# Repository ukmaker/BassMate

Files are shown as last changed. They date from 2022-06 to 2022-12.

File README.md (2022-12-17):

# BassMate

This is a simple drum machine and sequencer.

I want to be able to quickly create simple rhythm sequences to help me pratice electric bass, and was looking for something between a basic metronome and a full-fledged DAW.
The Drumbit online app (https://drumbit.app/) is pretty good, but having to point and click while playing an instrument is not tactile enough for me.
Accordingly, BassedMate (https://github.com/ukmaker/BassedMate) was born. This was the first iteration of the project, using a Teensy.

BassMate (this repo) is an evolution. I wanted to eliminate the VS1053 chip and I found the Electrosmith Daisy Seed (https://www.electro-smith.com/daisy/daisy)
which looked like it could do all the synthesis itself. I also found the MusicBoard project (https://github.com/julbouln/musicboard) which inspired me
to try to port to the Seed. This proved to be tricky, so I gave up (I'll try again one day!) and took a different path.

The UI of BassedMate felt a bit off, and when I came across the NavKey (https://coolcomponents.co.uk/products/i2c-navkey-7-function-joypad-black)
I thought I'd try something different. I also had an STM32F411 BlackPill (https://shop.pimoroni.com/products/stm32f411-blackpill-development-board?variant=39274213343315)
which has tons of memory and is really cheap.

So I remixed everything, sprinkled a new flavour of my GUI library (https://os.mbed.com/users/duncanFrance/code/SimpleGUI/) on the top and am happy with the result.

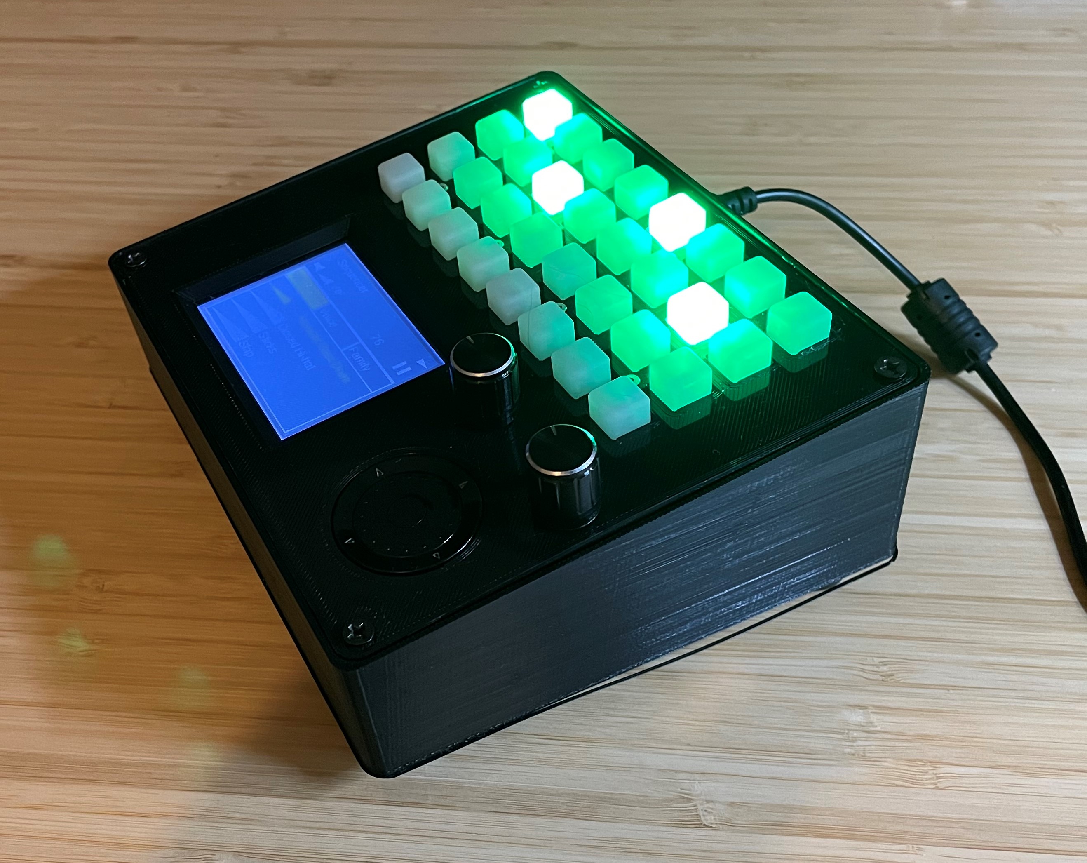
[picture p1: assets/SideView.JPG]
The Finished BassMate


BassMate in action(https://youtu.be/watch?v=EM4BZbcfi_k)

# Installation
This is a PlatformIO project.

Clone this repository somewhere, then get the git submodules:
```
  git clone git@github.com:ukmaker/BassMate.git
  cd BassMate
  git submodule init
  git submodule update
```

Open the folder in PlatformIO, build and deploy as usual.

I have an ST-LINK V2 clone which I use to program Blue- and Black-pills. I throroughly
recommend it since with it you get to debug with single-step etc.

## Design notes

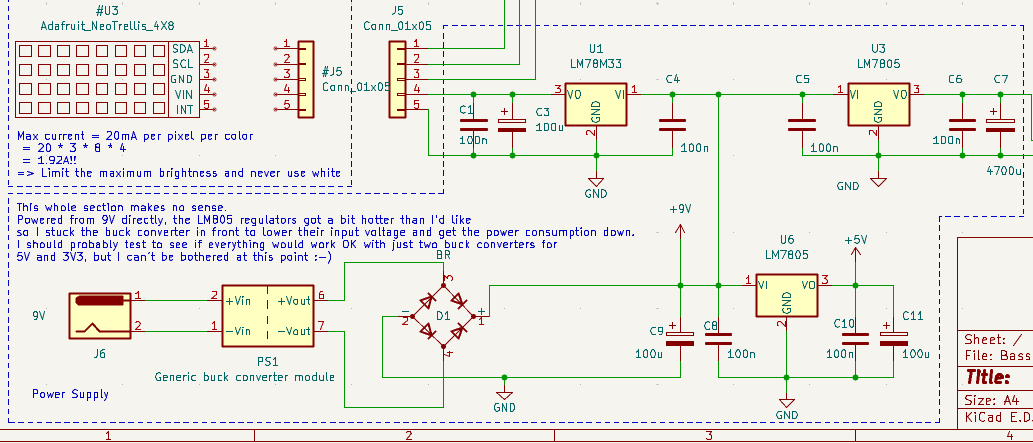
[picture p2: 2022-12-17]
assets/PSU.PNG

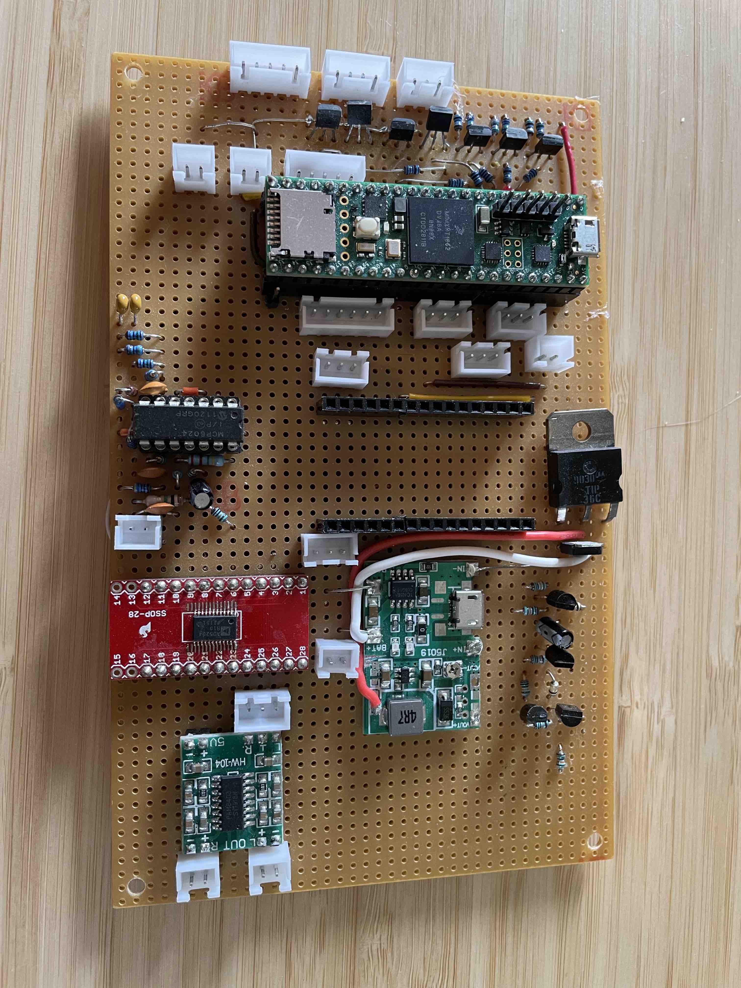
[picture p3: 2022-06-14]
assets/BassedMate-MainBoard.jpeg

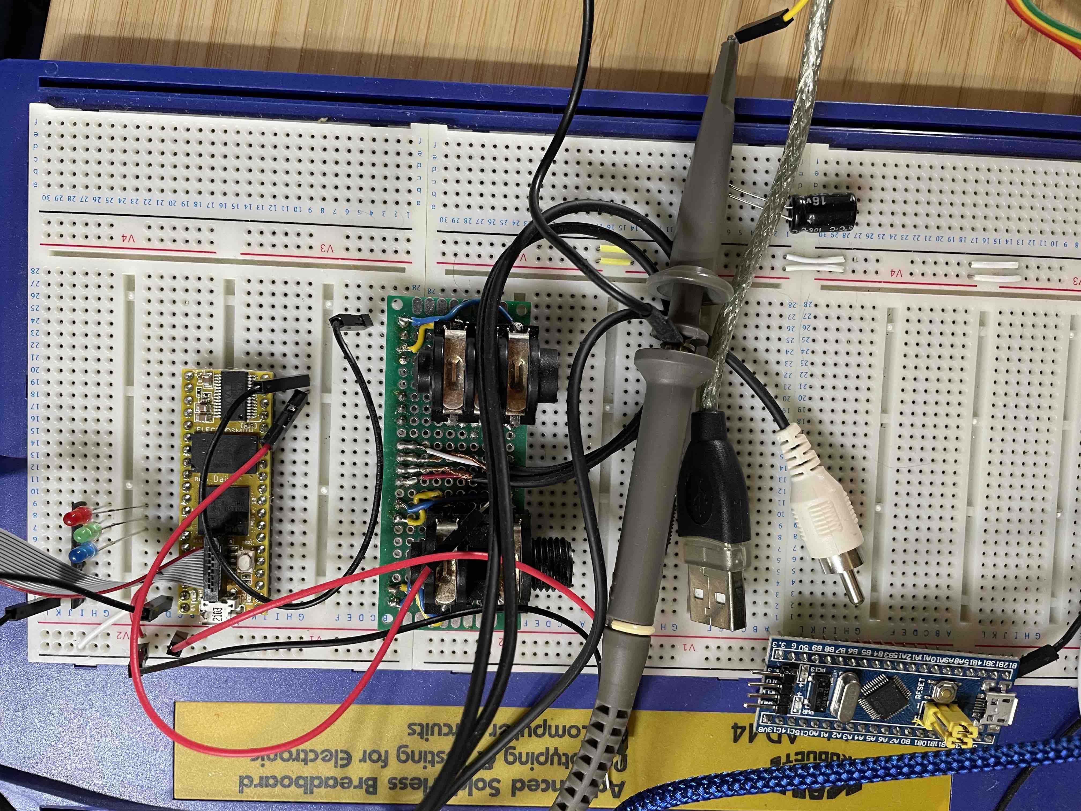
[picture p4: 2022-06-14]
assets/DaisySeed.jpeg

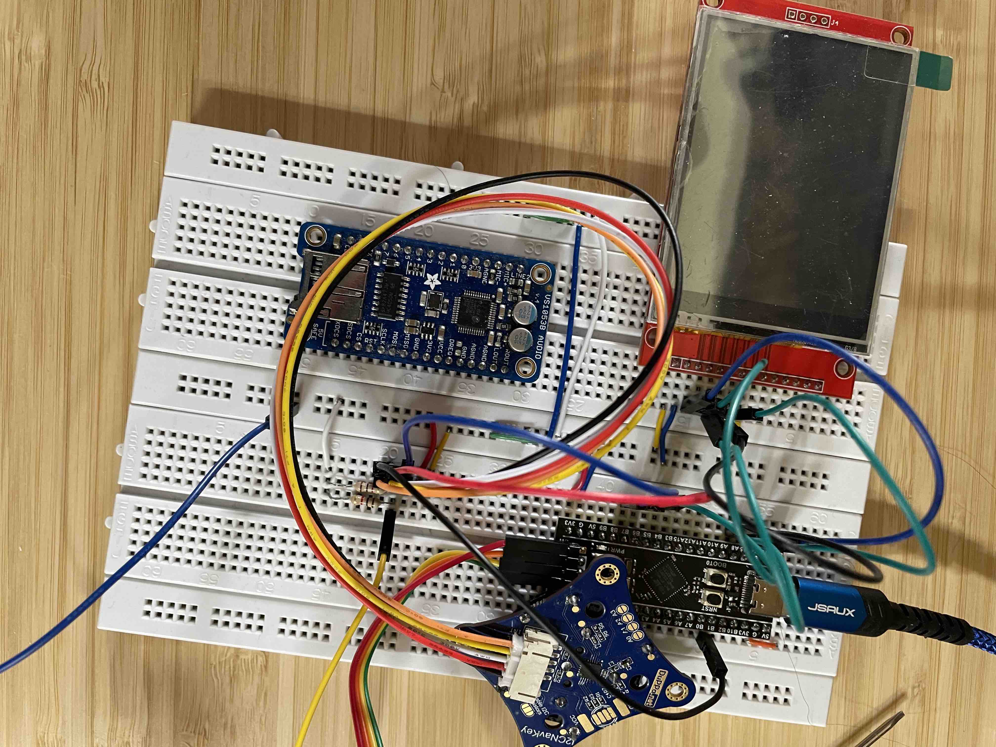
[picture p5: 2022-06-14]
assets/BlackPill.jpeg

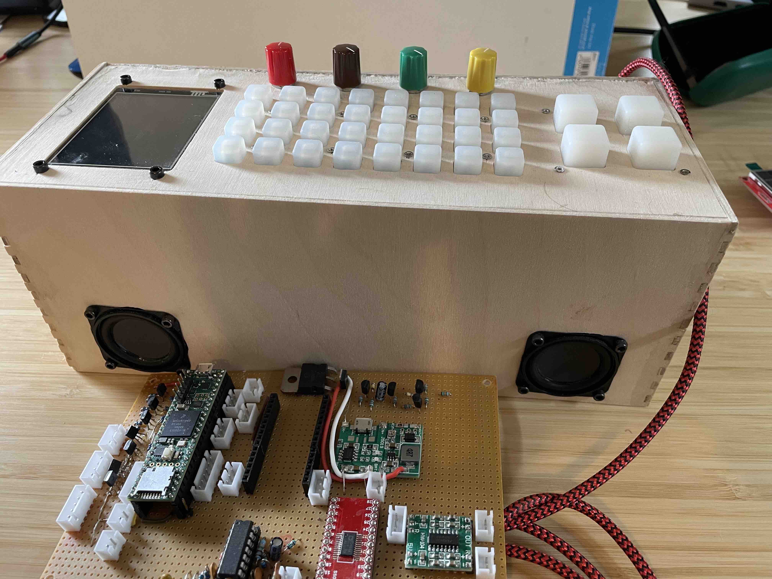
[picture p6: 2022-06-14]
assets/BassedMate-Side.jpeg

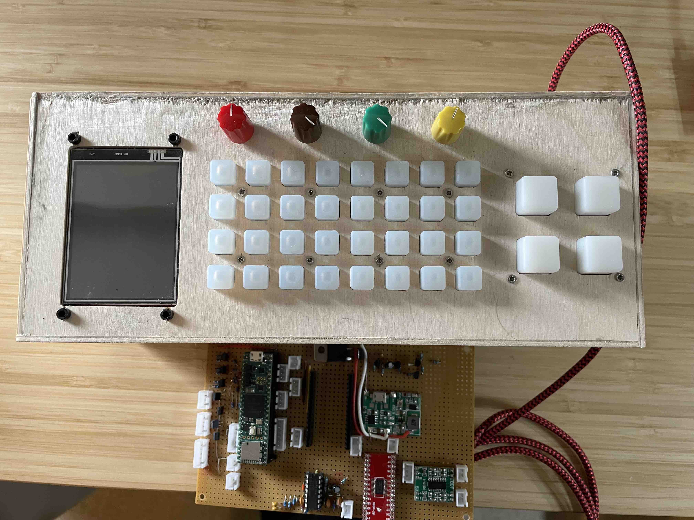
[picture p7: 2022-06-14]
assets/BassedMate-Top.jpeg

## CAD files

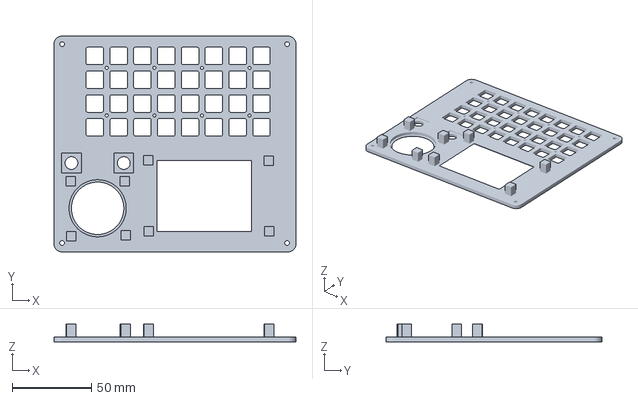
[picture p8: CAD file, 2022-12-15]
Cura/MU_FrontPanelV7.3mf
152.5 x 136.0 x 11.0 mm

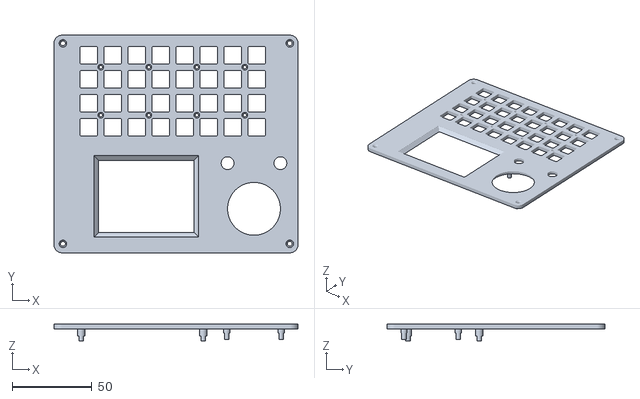
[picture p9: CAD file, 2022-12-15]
OpenSCAD/FrontPanelV7.stl
152.5 x 136.0 x 10.6

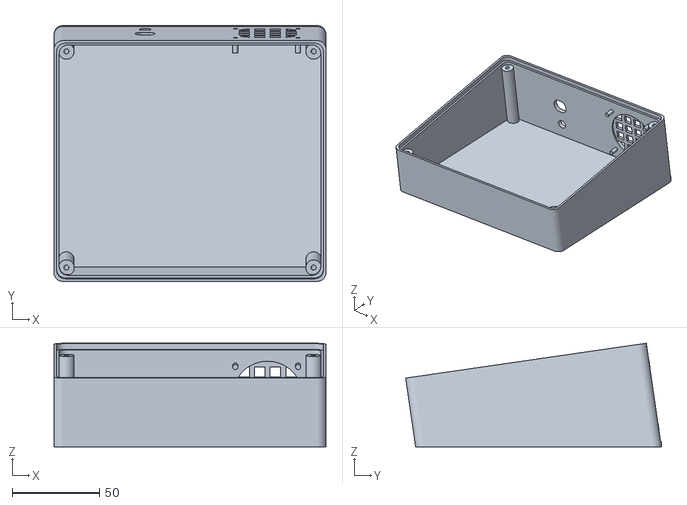
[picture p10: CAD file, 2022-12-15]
OpenSCAD/BassMate-BodyV7.stl
156.0 x 146.7 x 59.4

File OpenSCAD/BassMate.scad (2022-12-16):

include <FrontPanel.scad>
/**
* Uses the pre-release version 0.1 of ukmaker_openscad_lib
**/
include <ukmaker_openscad_lib/Boxes.scad>
$fn = 100;
/**
 * Model of an assembled BassMate
 **/

theta = asin ((20) / box_height);

LAYER_HEIGHT = 0.15;
thickness = 3;
screw_hole_dia = 3;
screw_hole_offset = thickness + 1.5 * screw_hole_dia - LAYER_HEIGHT;

power_socket_thread_dia = 11.5;
power_socket_flats = 10.5;
power_socket_height = 32;

headphones_dia = 6.8;
headphones_height = 15;


module headphone_socket() {

    translate([0,0,-LAYER_HEIGHT])
    cylinder(h = thickness *2, d= headphones_dia);

}

module power_socket() {
    // a cylinder with flats
    dy = (power_socket_thread_dia - power_socket_flats)/2;
    translate([0,0,-LAYER_HEIGHT])
    difference() {
        cylinder(h=thickness*2, d = power_socket_thread_dia);
        translate([-power_socket_thread_dia/2,-power_socket_thread_dia*1.5 + dy,-LAYER_HEIGHT])
        cube([power_socket_thread_dia,power_socket_thread_dia,thickness*3]);
        translate([-power_socket_thread_dia/2,power_socket_thread_dia*.5 - dy,-LAYER_HEIGHT])
        cube([power_socket_thread_dia,power_socket_thread_dia,thickness*3]);
    }
}

module
fitted_panel ()
{
  // THe front panel
  rotate ([ theta, 0, 0 ]) translate ([ thickness / 2, 0 / 2, 40 ]) panel ();
}

module
panel ()
{
  difference ()
  {
    option2 ();
    translate ([ -1.5, -1.5, 0 ])
        op_4_grid (box_width + 3.5, box_height + 3.5, screw_hole_offset,
                   screw_hole_offset, screw_hole_offset, screw_hole_offset)
            countersink (screw_hole_dia, thickness + 2 * LAYER_HEIGHT);
  }
}

module
body ()
{

  sloping_body (box_width + 3.5, box_height + 3.5, 40, 60, 3, 5, 3)
  {

    // Back panel cutouts are laid out on
    // a rectangle the width and rear_height of the boc
    // The sloping_body module rotates to the correct position
    // Speaker cutout on the right


    union() {
        translate ([ box_width - 30, 60 - 30, 0 ]) {                      
            speaker_grille_square(speaker_dia, thickness);
            // inset for the speaker rim
            translate([0,0,thickness-1])
            cylinder(h=speaker_lip+2*LAYER_HEIGHT, d=speaker_dia);
        }
        
        translate([box_width/2 - 24, headphones_height,0])
        headphone_socket();
        translate([box_width/2 - 24, power_socket_height,0])
        power_socket();
    }
    
     translate ([ box_width - 30, 60 - 30, 0 ]){
     union() {
        // holes are on a grid evenly spaced over the speaker
        l = speaker_mounting_hole_grid + 2 * speaker_mounting_hole_dia;
        w = l;
        offset = speaker_mounting_hole_dia/2;
        translate([-speaker_dia/2, -speaker_dia/2, 0])
        op_4_grid(l, w, offset, offset, offset, offset) {
            cylinder(h=speaker_mounting_hole_dia*3,d=speaker_mounting_hole_dia);
        }
    }
    }
  }
}

//fitted_panel ();
//power_socket();
body ();

// panel();

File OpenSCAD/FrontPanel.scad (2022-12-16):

LAYER_HEIGHT = 0.4;
/**
* Uses the pre-release version 0.1 of ukmaker_openscad_lib
**/
use <ukmaker_openscad_lib/Generics.scad>

use <ukmaker_openscad_lib/Standoffs.scad>

use <ukmaker_openscad_lib/TFTs.scad>


use <ukmaker_openscad_lib/I2CNavKey.scad>
include <ukmaker_openscad_lib/I2CNavKey.h>


panel_thickness = 3;

panel_rounding = 5;

trellis_button_side = 11;
trellis_button_grid = 15;
trellis_button_squish = 2;

trellis_width = 60;
trellis_height = 60;

trellis_rows = 4;
trellis_cols = 8;

tbt_side = 15.5;
tbt_grid = 25;

tft_w = 80;
tft_h = 50;

encoder_side = 12.5;
encoder_recess_depth = 1;
encoder_hole_dia = 8;


box_margin = 10;
box_width = tft_w + i2c_navkey_pcb_side + 3 * box_margin;
box_height =  trellis_button_grid * (trellis_rows-1)+ trellis_button_side + 2 * box_margin + tft_h + box_margin;

speaker_dia = 40;
speaker_lip = 1;
speaker_mounting_hole_dia = 3;
speaker_mounting_hole_grid = 33;

module button(h, w, r) {
    linear_extrude(height = h) rounded_square(h, w, r);
}

module buttons(h, w, r, s, rows, cols) {
    
    for(y = [0:rows-1]) {
        for(x = [0:cols-1]) {
            translate([x * s, y * s, 0])
            button(h,w,r);
        }
    }
    
}

module tft() {
    // overall 46x34 (56x34)
    // screen 35x28
    translate([0,0,-1]) {
        color("Red")
        linear_extrude(1)
        square([80,50]);
        
        color("Black")
        linear_extrude(4)
        translate([7.5,0,1])
        square([70,50]);
    }
}

module knob(c) {
    
    translate([0,0,3]) {
        translate([0,0,-10])
    cylinder(h=10, r=3.5);
    color("Grey")
    cylinder(h=18,r=6);
    translate([0,0,18])
    color(c)
    cylinder(h=1,r=6);
    }
}

module knobs() {
    knob("Red");
    
    translate([30,0,0])
    knob("Blue");
    
    translate([60,0,0])
    knob("Green");
    
    translate([90,0,0])
    knob("Black");
    
    
}
        
$fn=100;

module trellis() {
    buttons(trellis_button_side, trellis_button_side, 1, trellis_button_grid, 4, 8);
    
    screw_spacing = trellis_button_side+(trellis_button_grid-trellis_button_side)/2;
    trellis_side = trellis_button_grid*3 + trellis_button_side;
    
    op_4_grid(trellis_side,trellis_side,
    screw_spacing,screw_spacing,screw_spacing,screw_spacing)
    countersink(2,panel_thickness+LAYER_HEIGHT);

    translate([trellis_side+trellis_button_grid - trellis_button_side,0,0])
    op_4_grid(trellis_side,trellis_side,
    screw_spacing,screw_spacing,screw_spacing,screw_spacing)
    countersink(2,panel_thickness+LAYER_HEIGHT);
}

module control_buttons() {
    buttons(tbt_side, tbt_side, 1, tbt_grid, 2, 2);
}

module panel() {
    color("White")
    cube([260, 105, 2.5]);
}

module option1() {
projection()
difference() {
    translate([-10, -20, 0.1])
    panel();

    translate([0, - (tbt_side/2 + tbt_grid/2),0])
    translate([0, (trellis_button_side/2 + trellis_button_grid * 3/2), 0])
    control_buttons();

    translate([tbt_side * 2 + tbt_grid, 0, 0])
    trellis();

    translate([235,-15,0])
    rotate([0,0,90])
    tft();

    translate([70,70,0])
    knobs();
}
}

module i2c_navkey_locate() {
    translate([box_width - i2c_navkey_dia_1/2 - box_margin,i2c_navkey_dia_1/2 + box_margin,-0.1])
    children();
}

module option2() {
    // panel
    difference() {
        
         linear_extrude(height = panel_thickness) rounded_square(box_width, box_height, panel_rounding);

        //cube([box_width, box_height, 2.5]);
        tl = (box_width - trellis_width * 2) / 2;
        translate([tl, trellis_button_grid * 5 - 2, -0.1])
        trellis();
        
        // navkey hole
        i2c_navkey_locate()
        cylinder(h=panel_thickness+LAYER_HEIGHT,d=i2c_navkey_dia_2 + i2c_navkey_rim_clearance);
        
        i2c_navkey_locate()
        cylinder(h=i2c_navkey_joypad_rim_thickness + 1,d=i2c_navkey_dia_1 + 1);
        
        // TFT hole
        translate([box_margin,box_margin,-0.1]) {
        mnt_cutout_bezel_tft_2_8(thickness, panel_thickness+LAYER_HEIGHT);
        }
        
        // encoder holes
        translate([-encoder_side-4, i2c_navkey_pcb_side/2 + encoder_side/2 + 1, -0.1])
        i2c_navkey_locate() {
        cylinder(h=panel_thickness+LAYER_HEIGHT, d=encoder_hole_dia);
        translate([-encoder_side/2,-encoder_side/2,-LAYER_HEIGHT])
        cube([encoder_side,encoder_side,encoder_recess_depth+LAYER_HEIGHT]);
        
        }

        translate([encoder_side+4, i2c_navkey_pcb_side/2 + encoder_side/2 + 1, -0.1])
        i2c_navkey_locate() {
        cylinder(h=panel_thickness+LAYER_HEIGHT, d=encoder_hole_dia);
        translate([-encoder_side/2,-encoder_side/2,-LAYER_HEIGHT])
        cube([encoder_side,encoder_side,encoder_recess_depth+LAYER_HEIGHT]);
        }
    }
        
     
    i2c_navkey_locate() {
        mirror([0,0,1])
        i2c_navkey_melt_standoffs(i2c_navkey_board_offset - panel_thickness + 0.5, 4, LAYER_HEIGHT );
    }
    
    translate([box_margin,box_margin,-LAYER_HEIGHT]) {
       mirror([0,0,1])
        mnt_melt_bezel_tft_2_8(LAYER_HEIGHT);
    }
    translate([box_margin,box_margin,0]) {
        // Add the bezel
        mnt_bezel_tft_2_8(thickness, thickness);
    }
}

//option2();

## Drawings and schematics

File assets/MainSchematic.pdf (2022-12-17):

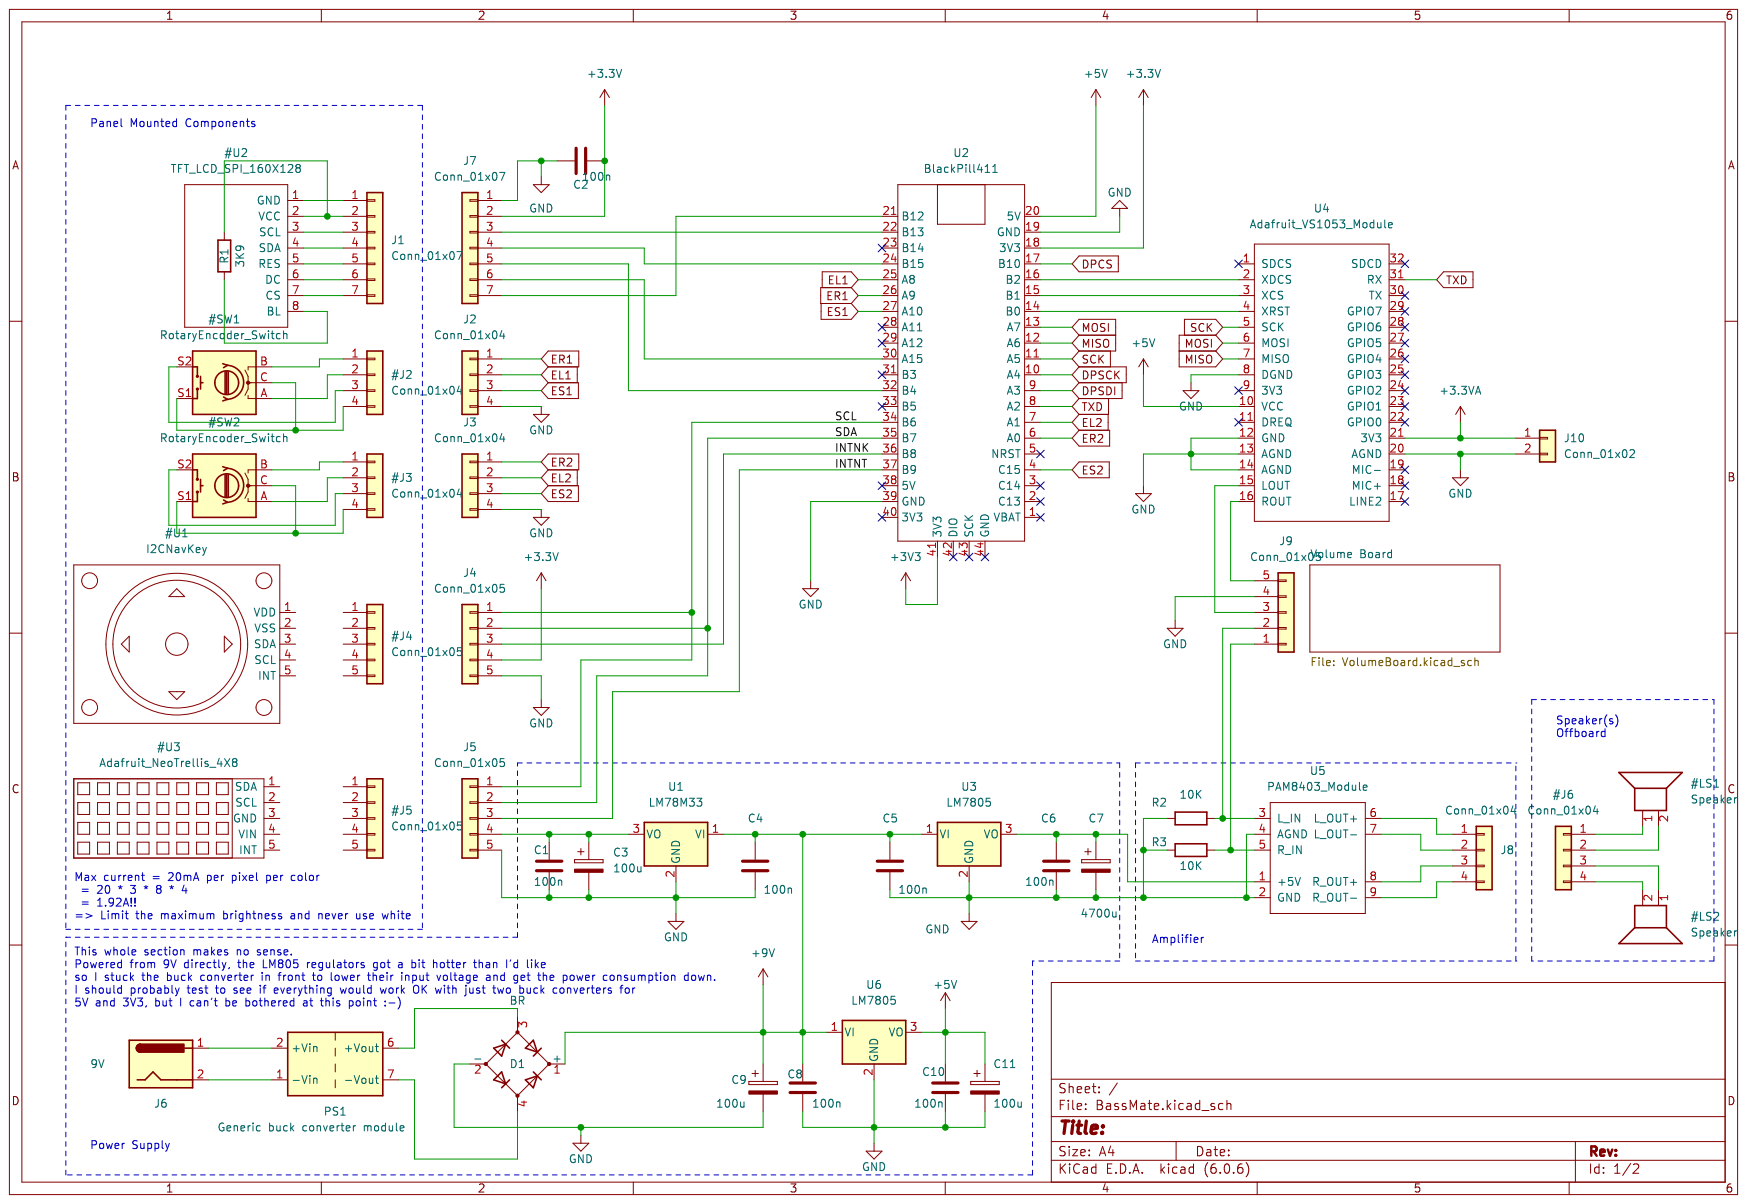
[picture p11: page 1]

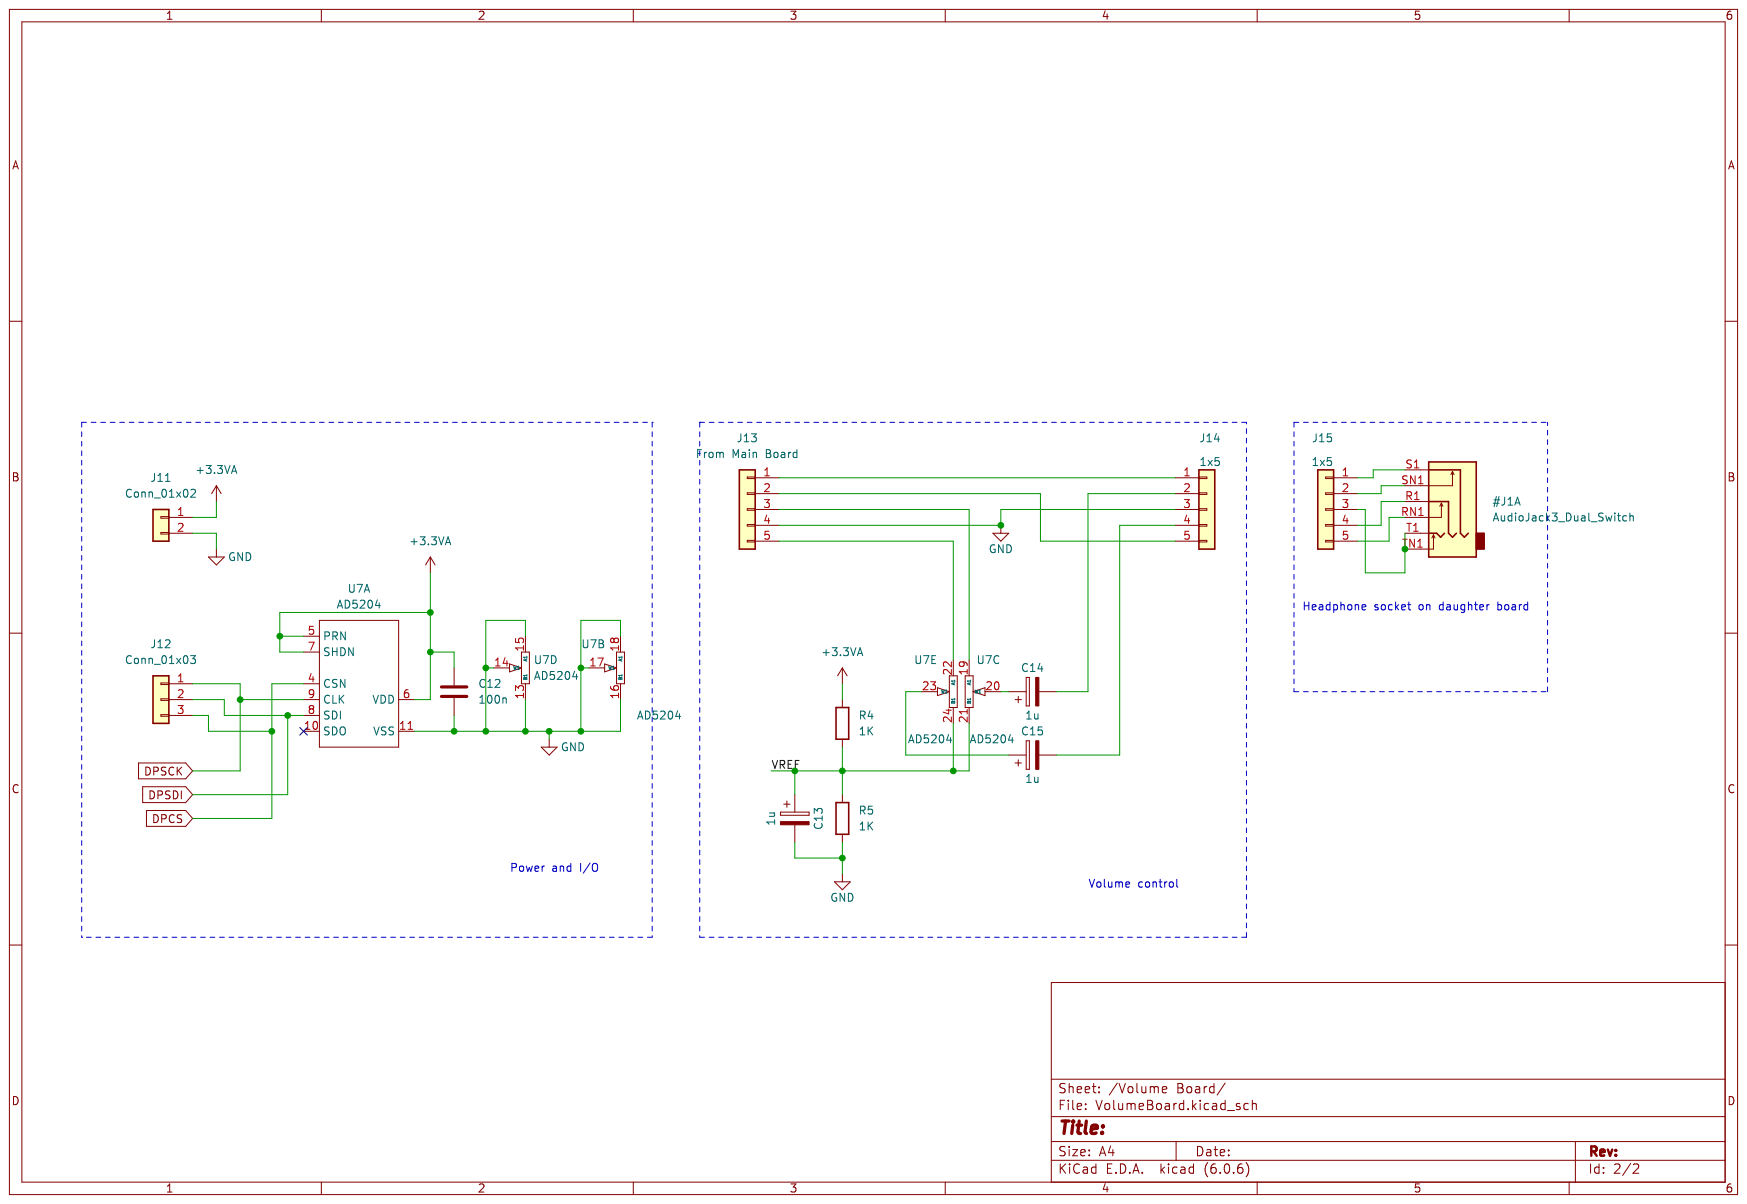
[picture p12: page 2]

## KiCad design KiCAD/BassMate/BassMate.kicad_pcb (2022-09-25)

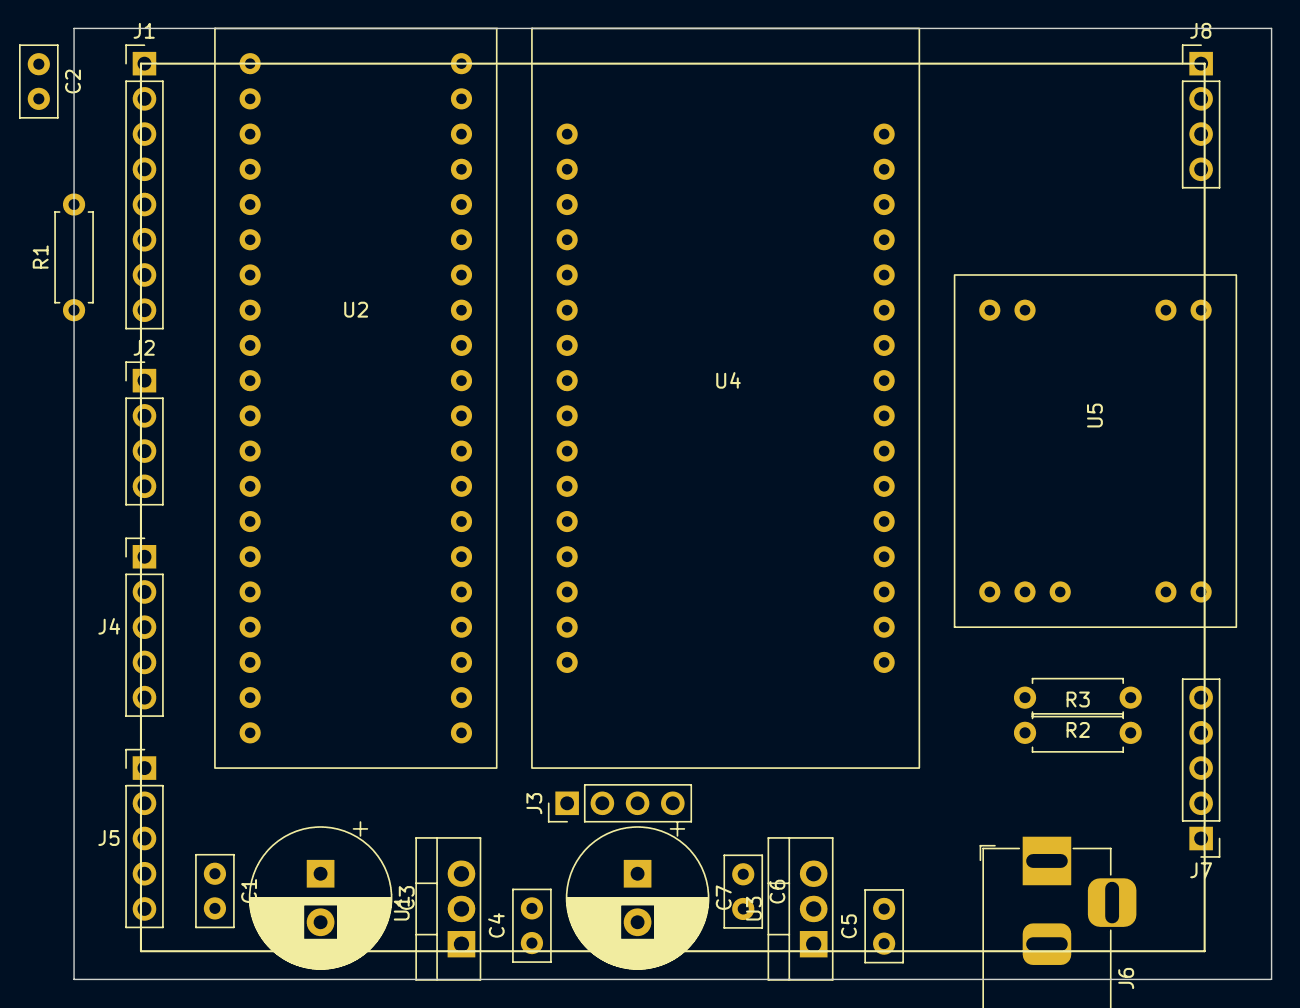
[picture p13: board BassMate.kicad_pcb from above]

Board: 2 copper layers, 86.4 x 68.6 mm, 23 parts (0 on the bottom side), 36 nets, no tracks yet.

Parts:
C1, C2, C4, C5, C6: C; C_Disc_D5.0mm_W2.5mm_P2.50mm
C3, C7: C_Polarized; CP_Radial_D10.0mm_P3.50mm
J1: Conn_01x08; PinHeader_1x08_P2.54mm_Vertical
J2, J3, J8: Conn_01x04; PinHeader_1x04_P2.54mm_Vertical
J4, J5, J7: Conn_01x05; PinHeader_1x05_P2.54mm_Vertical
J6: Barrel_Jack; BarrelJack_Horizontal
R1: 3K9; R_Axial_DIN0207_L6.3mm_D2.5mm_P7.62mm_Horizontal
R2, R3: R; R_Axial_DIN0207_L6.3mm_D2.5mm_P7.62mm_Horizontal
U1: LM78M33; TO-220-3_Vertical
U2: BlackPill411; BlackPill_STM32F411
U3: LM7805; TO-220-3_Vertical
U4: Adafruit_VS1053_Module
U5: PAM8403_Module

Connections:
+3.3V: C2.2, J1.2, J4.1, R1.2, U2.18 (3V3)
+5V: C6.1, C7.1, U2.20 (5V), U3.3 (VO), U4.10 (VCC), U5.1 (+5V)
+9V: C4.1, C5.1, J6.1, U1.1 (VI), U3.1 (VI)
/INTNK: J4.5, U2.36 (B8)
/INTNT: J5.3, U2.37 (B9)
/SCL: J4.4, J5.2, U2.34 (B6)
/SDA: J4.3, J5.1, U2.35 (B7)
EL1: J2.2, U2.25 (A8)
EL2: J3.2, U2.7 (A1)
ER1: J2.1, U2.26 (A9)
ER2: J3.1, U2.6 (A0)
ES1: J2.3, U2.27 (A10)
ES2: J3.3, U2.4 (C15)
GND: C1.2, C2.1, C3.2, C4.2, C5.2, C6.2, C7.2, J1.1, J2.4, J3.4, J4.2, J5.5, J6.2, J7.5, R2.1, R3.1, U1.2 (GND), U2.19 (GND), U2.39 (GND), U3.2 (GND), U4.8 (DGND), U4.12 (GND), U4.13 (AGND), U4.14 (AGND), U4.20 (AGND), U5.2 (GND), U5.4 (AGND)
MISO: U2.12 (A6), U4.7 (MISO)
MOSI: U2.13 (A7), U4.6 (MOSI)
unnamed: C1.1, C3.1, J5.4, U1.3 (VO)
unnamed: J1.3, U2.22 (B13)
unnamed: J1.4, U2.24 (B15)
unnamed: J1.5, U2.32 (B4)
unnamed: J1.6, U2.30 (A15)
unnamed: J1.7, U2.21 (B12)
unnamed: J1.8, R1.1
unnamed: J7.1, U4.16 (ROUT)
unnamed: J7.2, R2.2, U5.5 (R_IN)
unnamed: J7.3, U4.15 (LOUT)
unnamed: J7.4, R3.2, U5.3 (L_IN)
unnamed: J8.1, U5.6 (L_OUT+)
unnamed: J8.2, U5.7 (L_OUT-)
unnamed: J8.3, U5.8 (R_OUT+)
unnamed: J8.4, U5.9 (R_OUT-)
unnamed: U2.14 (B0), U4.4 (XRST)
unnamed: U2.15 (B1), U4.3 (XCS)
unnamed: U2.16 (B2), U4.2 (XDCS)
SCK: U2.11 (A5), U4.5 (SCK)
TXD: U2.8 (A2), U4.31 (RX)

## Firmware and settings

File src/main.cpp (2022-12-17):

#include "Controller.h"
#include "Events/NavKeyEventDispatcher.h"
#include "Hardware/STM_SPIDMA.h"
#include "STM32/STM32F411_Timer1Encoder.h"
#include "STM32/STM32F411_Timer2Encoder.h"
#include "Model.h"
#include "NavKeyView.h"
#include "NoteGrid.h"
#include <Wire.h>
#include "configuration.h"


using namespace bassmate;

SPIClass spi2(MOSI, MISO, SCK, SC_CS);
Adafruit_ILI9341_DMA tft = Adafruit_ILI9341_DMA(&spi2, SC_DC, SC_CS, SC_RESET);

volatile bool spiDmaTransferComplete = true;
STM_SPIDMA stmdma(&tft, LCD_DMA_BUFFER_SIZE, SPI2, DMA1_Stream4);

STM32F411_Timer1Encoder volumeEncoder(VOLUME_ENCODER_PUSH_PIN);
STM32F411_Timer2Encoder tempoEncoder(TEMPO_ENCODER_PUSH_PIN);

AD5204 digipot(DP_CS_PIN, DP_SCK_PIN, DP_SDI_PIN);

extern "C" {
void DMA1_Stream4_IRQHandler()
{
    HAL_DMA_IRQHandler(&stmdma._dma);
    // spiDmaTransferComplete = true;
}
}

extern "C" {
void HAL_SPI_TxCpltCallback(SPI_HandleTypeDef* hspi)
{
    spiDmaTransferComplete = true;
}
}

/*
 * Hardware interfaces
 */
SPIClass spi1(VS_MOSI, VS_MISO, VS_SCK);
Adafruit_NeoTrellis t_array[1][2] = {

    { Adafruit_NeoTrellis(0x2E), Adafruit_NeoTrellis(0x2F) }

};
Adafruit_MultiTrellis trellis((Adafruit_NeoTrellis*)t_array, 1, 2);
NoteGrid noteGrid(trellis, NT_INT);

/*
 * Model
 */
i2cNavKey navkey(0b0010000); /* Default address when no jumper are soldered */
VS1053 midi(VS_CS, VS_DCS, VS_RESET, spi1, Serial2);
Sequencer sequencer;
Storage* storage = new Storage();
uint8_t instrumentGroupMap[4];
Model model(navkey, NK_INT, midi, sequencer, storage, digipot);

/*
 * View
 */
NavKeyView view(&tft, noteGrid, storage);
NavKeyEventDispatcher navKeyEventDispatcher(&view);
Controller controller(model, view, noteGrid);
void UP_Button_Pressed(i2cNavKey* p)
{
    navKeyEventDispatcher.UP_Button_Pressed();
}
void DOWN_Button_Pressed(i2cNavKey* p) { navKeyEventDispatcher.DOWN_Button_Pressed(); }
void LEFT_Button_Pressed(i2cNavKey* p) { navKeyEventDispatcher.LEFT_Button_Pressed(); }
void RIGHT_Button_Pressed(i2cNavKey* p) { navKeyEventDispatcher.RIGHT_Button_Pressed(); }

void Encoder_Increment(i2cNavKey* p) { navKeyEventDispatcher.Encoder_Increment(); }
void Encoder_Decrement(i2cNavKey* p) { navKeyEventDispatcher.Encoder_Decrement(); }
void Encoder_Push(i2cNavKey* p) { navKeyEventDispatcher.Encoder_Push(); }
void Encoder_Release(i2cNavKey* p) { navKeyEventDispatcher.Encoder_Release(); }

void beatCallback(uint8_t beat) { controller.handleBeat(beat); }
void noteOnCallback(uint8_t beat, MIDINote note)
{
    controller.handleNoteOn(beat, note);
}
void noteOffCallback(uint8_t beat, MIDINote note)
{
    controller.handleNoteOff(beat, note);
}
void noteGridEventHandler(keyEvent e) { controller.handleNoteGridEvent(e); }
void noteGridKeyPressCallback(uint8_t x, uint8_t y)
{
    controller.handleNoteGridKeyPress(x, y);
}

void noteGridKeyLongPressCallback(uint8_t x, uint8_t y)
{
}

void setupNavKey()
{
    navkey.begin(i2cNavKey::FLOAT_DATA | i2cNavKey::WRAP_ENABLE | i2cNavKey::DIRE_RIGHT | i2cNavKey::IPUP_ENABLE);

    navkey.writeCounter((float)0); /* Reset the counter value */
    navkey.writeMax((float)0.95); /* Set the maximum threshold*/
    navkey.writeMin((float)0.05); /* Set the minimum threshold */
    navkey.writeStep((float)0.05); /* Set the step to 1*/

    navkey.writeDoublePushPeriod(5); // not used yet..
    navkey.onUpPush = UP_Button_Pressed;
    navkey.onDownPush = DOWN_Button_Pressed;
    navkey.onLeftPush = LEFT_Button_Pressed;
    navkey.onRightPush = RIGHT_Button_Pressed;
    navkey.onIncrement = Encoder_Increment;
    navkey.onDecrement = Encoder_Decrement;
    navkey.onCentralPush = Encoder_Push;
    navkey.onCentralRelease = Encoder_Release;
    navkey.autoconfigInterrupt();
}

void DMACallback(DMA_HandleTypeDef* _hdma) { spiDmaTransferComplete = true; }

void setup()
{

    noteGrid.attachEventHandler(noteGridEventHandler);
    noteGrid.attachKeyPressCallback(noteGridKeyPressCallback);
    noteGrid.attachKeyLongPressCallback(noteGridKeyLongPressCallback);
    sequencer.attachNoteOnCallback(noteOnCallback);
    sequencer.attachNoteOffCallback(noteOffCallback);
    sequencer.attachBeatCallback(beatCallback);

    volumeEncoder.onDecrement(&view, &NavKeyView::volumeUp);
    volumeEncoder.onIncrement(&view, &NavKeyView::volumeDown);
    volumeEncoder.onClick(&view, &NavKeyView::toggleMute);

    tempoEncoder.onIncrement(&view, &NavKeyView::faster);
    tempoEncoder.onDecrement(&view, &NavKeyView::slower);
    tempoEncoder.onClick(&view, &NavKeyView::togglePause);

    Serial.begin(9600);
    spi1.begin(48000000);
    spi2.begin(48000000);

    pinMode(VS_MOSI, OUTPUT);
    pinMode(VS_MISO, INPUT);
    pinMode(VS_SCK, OUTPUT);
    pinMode(VS_CS, OUTPUT);
    pinMode(VS_DCS, OUTPUT);
    pinMode(VS_RESET, OUTPUT);
    digitalWrite(VS_MOSI, HIGH);
    digitalWrite(VS_SCK, HIGH);
    digitalWrite(VS_CS, HIGH);
    digitalWrite(VS_DCS, HIGH);
    digitalWrite(VS_RESET, HIGH);
    pinMode(PA2, OUTPUT);

    pinMode(NK_INT, INPUT_PULLUP);
    pinMode(NT_INT, INPUT_PULLUP);
    pinMode(SC_RESET, OUTPUT);
    digitalWrite(SC_RESET, 0);

    pinMode(SCL, OUTPUT);
    pinMode(SDA, OUTPUT);
    digitalWrite(SCL, 1);
    digitalWrite(SDA, 1);


    volumeEncoder.setupIO(true);
    tempoEncoder.setupIO(true);

    Wire.begin((uint32_t)SDA, (uint32_t)SCL);
    Wire.setClock(400000);
    Serial2.begin(31250);

    setupNavKey();

    tft.setDMA(&stmdma);
    view.fontRenderer->setDMA(&stmdma);
    HAL_DMA_RegisterCallback(&stmdma._dma, HAL_DMA_XFER_CPLT_CB_ID, DMACallback);
    spiDmaTransferComplete = true;
    stmdma.begin();

    tft.begin(48000000);
    tft.setRotation(3);

    view.setController(&controller);

    view.begin();

    trellis.begin();
    noteGrid.setFlashBeat(true);
    noteGrid.begin();
    sequencer.setTempo(70);

    model.begin();
    controller.begin();
    volumeEncoder.begin();
    tempoEncoder.begin();
    pinMode(DP_SDI_PIN, OUTPUT);
}

void loop()
{
    volumeEncoder.tick();
    tempoEncoder.tick();
    view.run();
    model.run();
}

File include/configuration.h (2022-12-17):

#ifndef BASSMATE_CONFIG_H
#define BASSMATE_CONFIG_H

#define LEN(N) (sizeof(N) / sizeof(N[0]))

#define SCK PB13
#define MISO PB14
#define MOSI PB15
#define SC_CS PB12
#define SC_DC PB3
#define SC_RESET PB5

#define SCL PB6
#define SDA PB7
#define NK_INT PB8
#define NT_INT PB9

#define VS_MOSI PA7
#define VS_MISO PA6
#define VS_SCK PA5
#define VS_CS PB1
#define VS_DCS PB10
#define VS_RESET PB0

#define VOLUME_ENCODER_PUSH_PIN PA10
#define TEMPO_ENCODER_PUSH_PIN PC15

#define DP_CS_PIN PB10
#define DP_SCK_PIN PA4
#define DP_SDI_PIN PA3

#define LCD_DMA_BUFFER_SIZE 32768

#define LEFT_TRELLIS_ADDRESS 0x2E
#define RIGHT_TRELLIS_ADDRESS 0x2F

#endif

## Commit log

2022-06-14 Reimport after the great SSD meltdown
    [main.cpp]
2022-06-25 Added Timer class to handle smple timeout callback
2022-06-26 Refactored DMA support
2022-06-28 Initialise the timer properly for encoder
2022-09-25 Pushing latest changes. Hope this works...
    [BassMate.kicad_pcb, BassMate.kicad_sch, FrontPanel.scad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]
2022-10-30 Updated the 3D model for the box base
    [BassMate-Body-30_10_2022_1.stl, BassMate.scad, BassMate.stl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]
2022-10-31 Box updates
    [BassMate-Panel-31-10-2022_1.stl, BassMate.scad, FrontPanel.scad]
2022-12-15 The return of the AD5204 plus the two encoders
2022-12-15 Update schematic for AD5204. Better 3D case model.
    [BassMate-BodyV7.stl, BassMate-Panel-04-11-2022_1_bezel.stl, BassMate-Panel-05-11-2022_1_bezel.stl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]
2022-12-15 Removed old STLs and GCODE
    [BassMate-Body-30_10_2022_1.stl, BassMate-Panel-04-11-2022_1_bezel.stl, BassMate-Panel-05-11-2022_1_bezel.stl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]
2022-12-16 Started docs
    [BassMate.kicad_sch, BassMate.scad, FrontPanel.scad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]
2022-12-17 Converted most libs to git sbmodules
    [BassMate.kicad_sch, VolumeBoard.kicad_sch, configuration.h]
